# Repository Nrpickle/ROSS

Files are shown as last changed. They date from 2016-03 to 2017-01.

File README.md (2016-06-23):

# ROSS
Robotic Oceanographic Surface Sampler "lower level" code repo

This code covers anything that is not "user-servicable", which includes all of the firmware for the Kayak, as well as some miscellaneous lower level scripts for the Raspberry Pi.

## Software

All "software" for this project (e.g. things run on ground stations) can be found in the appropriate BitBucket repo. Contact [Nick McComb](mccombn@oregonstate.edu) or [Jasmine Nahorniak](mailto:jasmine@coas.oregonstate.edu) for access/more information.

## Firmware

"Firware" as defined for this project, is anything that runs on a microcontroller (e.g. doesn't use an Operating System). This Repo contains code for the following sub-projects:

### On/Off Switch

The primary On/Off switch for the kayak.

This box also provices a thrice-redundant GPS logging mechanism, that is independent of all other systems (besides power).

### Power Distribution Board (PDB)

This primarialy handles power distribution inside of the electrioncs box. 

For more information on this PCB, visit its dedicated documentation page [here](http://nickmccomb.net/printed-circuit-boards/ross-pdb).

For more information on the firmware for the microcontroller on this PCB, visit the subdirectory [here](https://github.com/Nrpickle/ROSS/tree/master/PDB/PowerDistribution).

### Winch / EBox Auxillary Programming

For more information on this PCB, visit its dedicated documentation page [here](http://nickmccomb.net/printed-circuit-boards/ross-ebox-auxillary).

### XTend Daughterboard

For more information on this PCB, visit its dedicated documentation page [here](http://nickmccomb.net/printed-circuit-boards/xtend-daughterboard).

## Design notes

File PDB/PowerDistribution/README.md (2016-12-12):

## Power Distribution Board

This board provides many features for the EBox for the ROSS project.

### Firmware Versioning

This page will describe released versions of this fiwmare and any important changes made. The firmware version will be bumped everytime a new version is pushed onto hardware.

#### Version .3

Released on 6/20/2016 for version 2.2 of the PDB hardware.

This is the first major implementation of the firmware, and while all the individual pieces of the firmware has been tested, ~~it hasn't made it out into the world yet~~ it was deployed in Alaska! This code has been extremely stable, with no bugs as of yet (December 2016).

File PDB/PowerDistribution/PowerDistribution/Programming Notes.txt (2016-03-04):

Settings Switch requires pull up resistors internal to uC

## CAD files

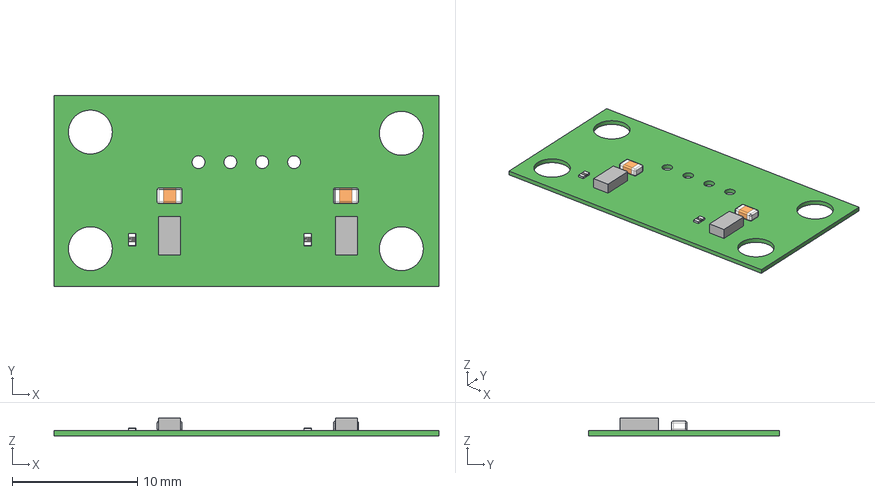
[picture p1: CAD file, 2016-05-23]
Winch/HallEffectSensors/HalleffectSensorsStepFile2.step
30.7 x 15.2 x 1.41 mm
Board
Extruded x 2
0402_SMD_Resistor x 2
User_Library-0805_SMD_Capacitor x 2

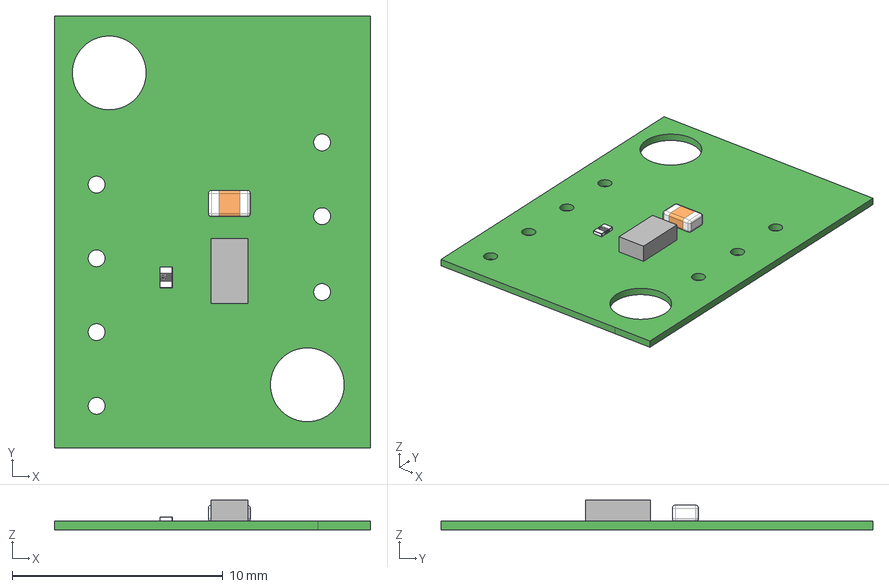
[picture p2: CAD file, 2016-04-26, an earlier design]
Winch/HallEffectSensors/HalleffectSensorsStepFile.step
15.0 x 20.5 x 1.41 mm
Board
Extruded
User_Library-0805_SMD_Capacitor
0402_SMD_Resistor

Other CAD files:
Winch/HallEffectSensors/HalleffectSensorsStepFile2_1.step
Winch/HallEffectSensors/HalleffectSensorsStepFileRev2.step

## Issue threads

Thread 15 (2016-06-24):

Debouncing winch hall effect sensors

Nrpickle, 2016-06-24:
Note "enhancement" tag.

This would essentially mean, that once the switch hits, you move a _small_ amount futher, so that you are for sure within the activation range of the hall effect, and not just on the edge. This would have to be done carefully, however.

Nrpickle, 2016-07-06:
Note this might actually be acheived by the inherient 500mS slowdown provided by the acceleration code...

Closed 2016-07-07.

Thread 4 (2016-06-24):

Arduino Servo Library doesn't output the values that the servo is expecting

Nrpickle, 2016-06-24:
See what the ESC is expecting, and add the optional min and max to the Arduino Servo library

https://www.arduino.cc/en/Reference/ServoAttach

See the notes on the Toughbook to see what the ESC is looking for by default, and compare this to the card

RobJShannon, 2016-06-27:
Values in milliseconds
Neutral: 1.479
Max Forward: 1.910
Max Reverse: 1.048
Largest Braking Threshold: .15
View current values: Prog -> Basic -> Current Settings

Closed 2016-06-29.

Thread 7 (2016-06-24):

Create "setWinchSpeed" function (or equivalent)

Nrpickle, 2016-06-24:
This function will take into account "previous speed" and "desired speed" and make a change in a time that is configurable via a #define at the top of the program.

Something approaching ["S-Curve Acceleration"](http://www.ni.com/product-documentation/4824/en/) should be implemented. It would be 100% desired to use a sin() function to do this, but it might not be realistic. Really, this depends on how fast your control loop is running.

Nrpickle, 2016-06-24:
Make sure that the "stop" position is configurable

Nrpickle, 2016-06-24:
I would use something like this:

```c
enum {UP, DOWN, STOP} //setWinchPower direction enum

/*
desiredPower : 0 - 100 (percent), value does not matter when desiredDIrection is STOP
desiredDirection: reference the setWinchPower direction enum
*/
void setWinchPower(uint8_t desiredPower, uint8_t desiredDirection);  //Set the winch power
```

Nrpickle, 2016-06-24:
The
```c
void sendStatus()
```
function should reference _this_ function's "current" status, instead of other variables in the program

Nrpickle, 2016-06-24:
A good backend for this could be

```c
struct {
  uint8_t currentPower;
  uint8_t currentDirection;
} winch;
```

if you wanted to implement it as a class, then `currentPower` and `currentDirection` would be private variables that can only be accessed by the `setWinchPower()` function, to ensure that it is the only thing that sets speeds. It should also be the _only_ function that calls `ESC.write()`.

Nrpickle, 2016-06-24:
The ```ServoWriteMicroseconds()``` Arduino function might be handy [[link]](https://www.arduino.cc/en/Reference/ServoWriteMicroseconds)

Nrpickle, 2016-06-24:
Ooh.

Or, how about this?

```c
struct {
  uint8_t currentPower;
  uint8_t prevPower;
  uint8_t currentDir;
  uint8_t prevDir;
  uint8_t upToDate;
} winch;

static void setWinchPower(uint8_t desiredPower, uint8_t desiredDirection){
  //This function needs to be be able to be called continuously throughout the exectution of the program
  //You may want the transition time to be ~1 second and you can't go blocking your program for that entire time.

  if(desiredPower == winch.currentPower && desiredDirection == winch.currentDir){
    //set prevPower = currentPower
    return;  //We are up to date
  }

  //Scenario: we are currently at DOWN 40 and want to go to UP 80, sinusodially.

  //Scale output power to 0 to 200 (100 being stop) then you want

  uint8_t powerDifference = //Then relate this to a number that's negative if the speed needs to "decrease" on the 200 number scale

  int powerToSend  = ((sin(out of phase -pi/2) + 1)/2 * powerDifference) + winch.prevPower; //This should give you a number that ranges from 0 to 100 that sinusodially goes between the previous power, and the one you want

  winch.currentPower = powerToSend;

  //actually output the power

  //check if the're the same
  //if(winch.currentPower = desiredPower){
  //  winch.prevPower = desiredPower;
  }
}

```

RobJShannon, 2016-06-28:
(sin(pi(t/500)-pi/2)+1)/2

Closed 2016-06-29.

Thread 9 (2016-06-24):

Revisit status messages

Nrpickle, 2016-06-24:
Status messages should be at least 2Hz (Jasmine doesn't have to send them back to the base station at that rate, but she could...)

These should include current position (as they currently do), and if possible a "speed (rpm)" would be desired.

Nrpickle, 2016-06-24:
I would also expand the status message, so we get more than "BUSY" or "NOT BUSY". I'd reccomend something like the following:

```c
enum {
  WAITING_FOR_PACKET,
  START/STOP,
  STOPPING,  //Maybe include this? Not sure.
  PROFILING - DOWN,
  PROFILING - UP,
  BAD_CHECKSUM
}
```

Nrpickle, 2016-06-24:
Also, this should probably include the Hall Effect sensor's satus, if possible.

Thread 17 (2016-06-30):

Hall Effect Status

RobJShannon, 2016-06-30:
Include HES state and error handle that returns in and maintains position if more than 6 revolutions go out without lower sensor engaging.

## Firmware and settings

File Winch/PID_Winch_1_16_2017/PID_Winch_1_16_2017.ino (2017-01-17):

#include <Statistic.h>

//Winch control version for use with the XLX green ESC
//Note: speeds and other variables need to be adjusted
//Note: code only checks for HES output when within slowing distance. May need to be changed.

#define DEBUG //Uncomment to print debugging information via serial
//#define TEST //Uncomment to run test with fake resistance
#define DOPID //Uncomment to run PID loop
Statistic myStats;
struct Winch_TYPE {
  uint8_t currentSpeed;
  uint8_t prevSpeed;
  uint8_t currentDir; // UP,DOWN,STOP defined in enum
  uint8_t prevDir;
  uint8_t prevDesiredDir;
  uint8_t prevDesiredSpeed;
} winch;

#include <Servo.h>
#include <Encoder.h>
#include <Timer.h>
#include <PID_v1.h>

Servo ESC; //Create ESC object
Encoder winchEncoder(3,2); //Create encoder object
Timer statusTimer; //Create a timer for sending status messages
  
enum{ //Assign integer values to each direction
  UP,
  DOWN,
  STOP
};

enum{  //Assign integer values to each state
  CHECK_BUFFER,
  CONTROL_WINCH,
  MAINTAIN
};

#define ENCODER_OPTIMIZE_INTERRUPTS
//Maximum, minimum, and neutral pulse widths in microseconds 
//ESC 1: 1910, 1479, 1048
//ESC 2: 1980, 1534, 1086
//ESC 3 (green XLX 12/1/2016): 2405, 1475, 545  
#define MAX_FORWARD 2405 //Maximum, minimum, and neutral pulse widths in microseconds
#define NEUTRAL 1475
#define MAX_REVERSE 545
#define REV(x) 3936*x //Converts revolutions into encoder pings

//Speed constants
#define SLOW_DIST 15 //Distance in revolutions from full upright to begin changing winch speed in
#define LIFT_SPEED 45//Speed for lifting the A-frame when finishing a profile
#define MAINTAIN_SPEED 40 //Speed for lifting the A-frame when maintaining
#define FAST_IN_SPEED 50 //Speed for returning fast AND maintaining
#define SLOW_IN_SPEED 30 //Speed for returning slow AND maintaining

//Define remote start/stop pins
#define remoteStartPin 5
#define remoteStopPin 6
#define remoteStartLED 7
#define remoteStopLED 8
#define startTime 750 //How long remote start is held HIGH in milliseconds
//Define sensor pins
#define downPin 10//Hall Effect sensor indicating lowered position (no longer used)
#define downLED 13
#define upPin 11 //Hall Effect sensor indicating upright position
#define upLED 15
//Define analog pins
#define resistancePin 8 //fishing rod strain gauge resistance (analog pin)

//Define PID tuning parameters (must be >= 0)
//error = desired - input
//output = Kp*error + integral(Ki*error) - Kd*(input - lastinput)
double Kp = .035; // proportional - reacting to current error
double Ki = 0; // integral - reacting to error over time
double Kd = 0; // derivative - reacting to change in error
const int KDir = DIRECT;  // if DIRECT, +INPUT leads to +OUTPUT, if REVERSE, +INPUT leads to -OUTPUT

// resistance calibration settings for the fishing rod
double straightResistance = 0; //ohms - rod straight (no tension) (Daywa Custom Design (Dark Grey) - 800)
const double stopResistance = 0; //ohms - position of rod to send stop command (getting too slack) (should be about 722)
double bentResistance = 0; //ohms - rod bent (full tension) (should be about 620)
double desiredResistance = 600; //ohms - resistance to attempt to maintain at all times
double resistance = 0;  //TEST
double rodMultiplier = 0.95;

// frequency of status messages in ms
#ifdef DEBUG
    int statusFrequency = 1000;
#else
    int statusFrequency = 1000;
#endif

const double RAMP_TIME = 500; //Time it takes to change speed in milliseconds
const double RAMP_TIME_DOWN = 3000; //Ramp time at beginning of profile to prevent tangling
const float pi = 3.14159;
uint64_t t0 = 0; //Beginning time for speed change
int16_t speedDifference = 0; //Difference between desired and current speed
int parameters[7];
int incomingByte = 0;

int state = CHECK_BUFFER;
int firstbyte; //First byte to check consistency with RPI
int secondbyte = 0x00; //Second byte to check consistency with RPI
int header = 0;
int upperByte;
int lowerByte;

int checksum;
int buffSize = 0;
int speedOut;
int speedIn;
double speedTry;
long long depth;
bool motorRunning = false;
bool depthReached = false;
bool halt = false;
bool returned = true;
bool dataCorrupted = false;
bool go = false; //Used to specify if buffer is synced with RPI
bool kickstart = true; //used to kickstart pid for sinusoid

int timerActivate = 0; //Using this to piggyback off the timer for the status message

int warningCounter = 0; //used to tell if the rod has lost tension for a certain amount of time

int avgvalue = 0; //used for the stats values to average the resistance for min/max values

PID rodPID(&resistance, &speedTry, &desiredResistance, Kp, Ki, Kd, KDir); //Create PID object and links


void setup() {
  // put your setup code here, to run once:
  Serial1.begin(57600);
  #ifdef DEBUG
    Serial.begin(9600);
  #endif
  winch.currentSpeed = 100; //Initialize all struct values to stationary
  winch.prevSpeed = 100;
  winch.currentDir = STOP;
  winch.prevDir = STOP;
  winch.prevDesiredDir = STOP;
  winch.prevDesiredSpeed = 0;
  //Set pin modes
  pinMode(remoteStartPin, OUTPUT);
  pinMode(remoteStopPin, OUTPUT);
  pinMode(remoteStartLED, OUTPUT);
  pinMode(remoteStopLED, OUTPUT);
  pinMode(upLED, OUTPUT);
  pinMode(downLED, OUTPUT);
  pinMode(downPin, INPUT);
  pinMode(upPin, INPUT);
  //Initialize pin states
  digitalWrite(remoteStartPin, LOW);
  digitalWrite(remoteStopPin, HIGH);
  digitalWrite(remoteStartLED, LOW);
  digitalWrite(remoteStopLED, LOW);
   
  statusTimer.every(statusFrequency, sendStatus, sendWarning); //Send a status message every X milliseconds and send a warning if the rod has been straight for too long
  
  ESC.attach(9, MAX_REVERSE, MAX_FORWARD); //Connect ESC to pin 9 with maximum and minimum puse width values
  ESC.writeMicroseconds(NEUTRAL); //Start the winch in neutral
  delay(5000); //Allow ESC to receive neutral signal for proper amount of time

  rodPID.SetOutputLimits(-10, 10); //output given by PID controller is constrained (Should be used to change and input to the plant system)
  rodPID.SetMode(AUTOMATIC);

  while(!digitalRead(upPin) != true){ //waits for the A-frame to be all the way up
    changeSpeed(LIFT_SPEED, UP); //if for some reason it isn't we set the speed to go up 
    Serial1.println("Initial lift.");
  }
  changeSpeed(0, STOP);
  winchEncoder.write(0);
  returned = true;
  myStats.clear(); //Forces the "myStats" constructor to start with no data
}

void loop() {
  statusTimer.update();
  //checkResistance();  // keep this commented - it won't work with the PID loop 
  myStats.clear(); //make sure to clear old data from myStats constructor
  switch(state){
    
    case CHECK_BUFFER:

       if(buffSize == 7){ //Update parameters if the serial buffer is full (new packet fully received)
         updateParameters();
         Serial.println(header);
       }
       state = CONTROL_WINCH;
       
       break;
     
    case CONTROL_WINCH:
      if(header == 0xCD) //Set PID values using speedOut and speedIn (parameters[1-2]
      {
        Kp = speedOut/100;
        Ki = speedIn/100;
        header = 0;
      }

      if(header == 0xCA){ //calibration straight
        avgvalue = 0;
        while(avgvalue == 0){
          for(int i = 0; i < 50; i++){
            myStats.add(analogRead(resistancePin));          
            delay(100);
          }
          avgvalue = myStats.average() + 1;
          Serial.println(avgvalue);
        }
        straightResistance = avgvalue - 1;
        if(bentResistance > 0){
          desiredResistance =  straightResistance - ((straightResistance - bentResistance) * rodMultiplier); 
          
        }
        #ifdef DEBUG
          Serial.print("CAL STRAIGHT: ");
          Serial.println(straightResistance);
          Serial1.print("CALSTRAIGHT ");
          Serial1.println(straightResistance);
          Serial.print("DESIREDRESISTANCE: ");
          Serial.println(desiredResistance);
          //Serial1.println("TESTTESTTESTTEST");
        #endif
        header = 0; //stop entering this if statement
      }

      if(header == 0xCB){ //calibration bent
        avgvalue = 0;
        while(avgvalue == 0){
          for(int i = 0; i < 50; i++){
            myStats.add(analogRead(resistancePin));          
            delay(100);
          }
          avgvalue = myStats.average() + 1; //Make sure the code exits the while loop
        }
        bentResistance = avgvalue - 1; //Remove the extra 1 value
         if(straightResistance > 0){
          desiredResistance =  straightResistance - ((straightResistance - bentResistance) * rodMultiplier); //Calculates our tension value we want. It will be 95% of the difference between our max and min values that were calibrated     
           }
        #ifdef DEBUG
          Serial.print("CAL BENT: ");
          Serial.println(bentResistance);
          Serial1.print("CALBENT ");
          Serial1.println(bentResistance);
          Serial.print("DESIREDRESISTANCE: ");
          Serial.println(desiredResistance);
        #endif
        header = 0; //stop entering this if statement
       }
       
       if(header == 0xCC){ //STOP:Halt
         changeSpeed(0, STOP);
         halt = true;
         depthReached = true;
         returned = true;
       }
         
       if(header == 0xAA){//STOP:Return at full speed
         //changeSpeed(0, STOP);
         depthReached = true;
         if(!digitalRead(upPin) == false) //Return the winch to its upright position and maintian (only if the winch isn't already up)
           changeSpeed(FAST_IN_SPEED, UP);
         if(!digitalRead(upPin) == true && winchEncoder.read() <= REV(SLOW_DIST)){
           changeSpeed(0, STOP);
           winchEncoder.write(0);
           returned = true;
           header = 0; //stop entering this if statement
         }
       }
       
       if(header == 0xBB){//STOP:Return slower
         //changeSpeed(0, STOP);
         depthReached = true;
         if(!digitalRead(upPin) == false) //Return the winch to its upright position and maintian
           changeSpeed(SLOW_IN_SPEED, UP);
         if(!digitalRead(upPin) == true && winchEncoder.read() <= REV(SLOW_DIST)){
           changeSpeed(0, STOP);
           winchEncoder.write(0);
           returned = true;
           header = 0; //stop entering this if statement
         }
       }
       
       if(header == 0xEE)//Stop the motor
         remoteStop(); 
       
       if(header == 0xDD)//Start the motor
         remoteStart();
       
       if(header == 0xDA)//Take a profile - normal operation
         takeProfile();
         
       if(returned == true && halt == false) //If all the other header values aren't true then go to this
       {
         state = MAINTAIN;
       }
       else
       {
         state = CHECK_BUFFER;
       }
       break;
     
    case MAINTAIN:
       kickstart = true;
        //Serial.println("MAINTAIN");
       //if(!digitalRead(upPin) == false || !digitalRead(downPin) == true)
       if(!digitalRead(upPin) == false)   //if the winch isn't in the up position then
        { 
         changeSpeed(MAINTAIN_SPEED, UP);//change our speed to go up at the maintain speed
         //Serial.println("I'M SETTING THE SPEED TO BE UP AT MAINTAIN SPEED");
       }
       else{
         //Serial.println("I'VE SET THE SPEED TO BE 0 AND STOPPED");
         changeSpeed(0, STOP); //when we've reached the top then stop
         winchEncoder.write(0); //reset the winch encoder counter to 0
         //Serial.println("I'VE RESET THE WINCH COUNTER");
         returned = true;
       }
       state = CHECK_BUFFER;
       break;
   
  } //end switch
  delay(2);
} //end loop

void changeSpeed(uint8_t newSpeed, uint8_t newDir)  {
  double ramp = RAMP_TIME;
  if(newDir == DOWN)
    ramp = RAMP_TIME_DOWN;

  //Serial.println(newSpeed);
  //If we want to go UP
  if(newDir == UP){
    newSpeed = 100 - newSpeed;
    //winch.currentDir = UP;
  }
  //If we want to go down
  else if(newDir == DOWN){
    newSpeed = 100 + newSpeed;
    //winch.currentDir = DOWN;
  }
  //Else we want to STOP
  else{
    newSpeed = 100;
    //winch.currentDir = STOP;
  }
  #ifdef DEBUG
    //Serial1.print("[Desired: ");
    //Serial1.print(newSpeed);
    //Serial1.print(" Current: ");
    //Serial1.print(winch.currentSpeed);
    //Serial1.println("]");
  #endif
  

  //Check if no change is needed (if we are going the desired speed and direction)
  if(newDir == winch.currentDir && newSpeed == winch.currentSpeed)
  {  //If the command is to continue moving the same speed and direction then don't do the sinusoid
    winch.prevSpeed = winch.currentSpeed;
    winch.prevDesiredSpeed = newSpeed; //Next time we write a new speed we know it will be at t0, the beginning of a speed change
    winch.prevDesiredDir = newDir;
    #ifdef DEBUG
      //Serial1.println("[REACHED END CASE]");
    #endif
    return;   //...return without altering speed (And ignoring EVERYTHING below this)
  }

    //This will catch if we have gotten to this spot while the previous call to the function was "no change requested"
    if(winch.prevDesiredSpeed != newSpeed && winch.prevDesiredDir != newDir)
    {  //Even though the newspeed = prevspeed will be true, this only activates when changing direction
      //If that's the case, then we want to initialize the acceleration
      t0 = millis();  //Start a timer for the sinusoid function
      speedDifference = newSpeed - winch.prevSpeed;
      //Avoid errors comparing different data types. If the difference is a negative value, make it slightly more negative. Same for a positive speed difference. 
      if(speedDifference < 0)
        speedDifference -= 1;
      else if (speedDifference > 0)
        speedDifference += 1;
    }   
    if(kickstart == true) {
    uint64_t deltaT = millis() - t0; //Keep relative time for the sinusoid (this will not activate if we've reached the speed we want
    winch.currentSpeed = (double)winch.prevSpeed + (double)speedDifference*.5*(1-cos((pi*(double)deltaT)/ramp));//Accelerate sinusoidally
    }
    else{
      winch.currentSpeed = newSpeed;
    }

  constrain(winch.currentSpeed, 0, 200); //Do not write above or below the maximum pulse widths
 // Serial.println("SPEED IS:   ");
 // Serial.println(winch.currentSpeed);
  uint16_t speedToWrite = map(winch.currentSpeed, 0, 200, MAX_REVERSE, MAX_FORWARD); //Convert from sinusoid magnitude to pulse width
  ESC.writeMicroseconds(speedToWrite); //Write the scaled value
  #ifdef DEBUG
    //Serial1.println(speedToWrite);
  #endif 
  if(winch.currentSpeed == newSpeed)
    winch.prevSpeed = newSpeed; //Set the starting point for the next speed change
    
  if(winch.currentSpeed > 100)
    winch.currentDir = DOWN;
  else if(winch.currentSpeed < 100)
    winch.currentDir = UP;
  else if(winch.currentSpeed == 100)
    winch.currentDir = STOP;
    
  winch.prevDesiredSpeed = newSpeed; //Next time we write a new speed we know it will be at t0, the beginning of a speed change
  winch.prevDesiredDir = newDir;
}

void serialEvent1()
{
  if(Serial1.available()){
   
   if (go){ //check to see if the go statement is true (Data is synced)
     parameters[buffSize] = Serial1.read();
     buffSize++;
   }
   else{  //If the go statement isn't true, wait until the data is synced and then make go statement true

        firstbyte = Serial1.read(); //Read the first byte coming from the RPI
    
        if((firstbyte == 255) && (secondbyte == 255)){
          go = true;
        }
        else{
          secondbyte = firstbyte; //store value to check again
          go = false;
        }
   }
  }
}

void updateParameters(){
  header = parameters[0];
  speedOut = parameters[1]; //Save array contents to corresponding variables
  speedIn = parameters[2];
  upperByte = parameters[3];
  lowerByte = parameters[4];
  checksum = parameters[5];
  Serial.println(header);
  Serial.println(speedOut);
  Serial.println(speedIn);
  Serial.println(upperByte);
  Serial.println(lowerByte);
  Serial.println(checksum);
  buffSize = 0; //Reset buffer size and control variables
  kickstart = true; //reset kickstart for another profile
  go = false; //reset the go condition to check data again for consistency 
  secondbyte = 0x00; // reset second byte to zero
  warningCounter = 0;
  depthReached = false;
  halt = false;
  if(checksum == (((speedOut ^ speedIn) ^ upperByte) ^ lowerByte)){
    upperByte = upperByte << 8;
    depth = upperByte + lowerByte;
    depth = REV(depth); //pings/revolution
    speedOut = speedOut*100/254; //Scale from 0-254 to 0 - 100
    speedIn  = speedIn*100/254; //Scale from 0-254 to 0 - 100
    dataCorrupted = false;
  }
  else{
    depth = 0;
    speedOut = 0;
    speedIn = 0;
    dataCorrupted = true;
  } 
}

void sendStatus(){
  Serial1.print("STATUS ");
  Serial.println("STATUS");
  if(dataCorrupted == false){
    if(returned == true){
      Serial1.print("1  "); //Ready
    }
    else{
      Serial1.print("0  "); //Busy
    }
  }
  else{
    Serial1.print("3  "); //Data corrupted
    dataCorrupted = false;
  }
  Serial1.print("Dir ");
  if(winch.currentDir == UP)
    Serial1.print("up  ");
  else if(winch.currentDir == DOWN)
    Serial1.print("down  ");
  else if(winch.currentDir == STOP)
    Serial1.print("stationary  ");
 
  Serial1.print("Rev ");
  long long pingsFromSurface = winchEncoder.read();
  pingsFromSurface = pingsFromSurface/3936;
  long revsFromSurface = (long) pingsFromSurface;
  Serial1.print(revsFromSurface);
  Serial1.print(" Kp ");
  Serial1.print(Kp);
  Serial1.print(" Ki ");
  Serial1.print(Ki);
  Serial1.print(" Res ");
  Serial1.println(analogRead(resistancePin));
  
  
  Serial.print("Rev ");
  Serial.println(revsFromSurface);
  Serial.print("Speed: ");
  Serial.println(winch.currentSpeed);
  Serial.print("Res: ");
  Serial.println(analogRead(resistancePin));
  Serial.print("Desired Resistance:  ");
  Serial.println(desiredResistance);
  
  #ifdef DEBUG
    //Serial.print("[Resistance: ");
    //Serial.print(resistance);
    //Serial.println("]");
  #endif
}

inline void remoteStart(){
  if (motorRunning == false){ //Prevent remote start from executing if motor already running
    digitalWrite(remoteStopPin, LOW);
    digitalWrite(remoteStartPin, HIGH);
    digitalWrite(remoteStartLED, HIGH);
    delay(startTime);
    digitalWrite(remoteStartPin, LOW);
    digitalWrite(remoteStartLED, LOW);
    motorRunning = true;
  }
}

inline void remoteStop(){
  if(motorRunning == true){
    digitalWrite(remoteStopPin, HIGH);
    digitalWrite(remoteStopLED, HIGH);
    motorRunning = false;
  }
}

void takeProfile(){
   if(depthReached == false){
//    if(!digitalRead(downPin) == false){//Slowly let A-frame down from upright position
//      changeSpeed(30, DOWN);
//      returned = false;
//    }
     if((winchEncoder.read() < depth)){
       doPID(speedOut, DOWN);
       returned = false;
     }
     else if(winchEncoder.read()>= depth){
       changeSpeed(0, STOP);
       Serial.println("I'VE REACHED THE END OF THE PROFILE, SET THE SPEED TO 0 AND STOP"); //debug change speed when reached depth desired
       depthReached = true; 
       returned = false;
       kickstart = true;
     }
  }
  else if((depthReached == true) && (halt == false)){
    
    
      if(!digitalRead(upPin) == true){ //Stop when A-frame is in full upright position
        changeSpeed(0, STOP);
        winchEncoder.write(0); //Account for line stretching - reset after each cast
        returned = true;
        Serial.println("DONE PROFILE");
        header = 0; //Will go straight into maintain mode rather than use take profile to maintain position
      }
     
      else if(winchEncoder.read() > REV(SLOW_DIST)){ //checks to see if we're within the slow_dist revolutions (5 revs)
      changeSpeed(speedIn, UP);
      //Serial.println("Going speedIn in the UP direction"); //Debug speed in
      returned = false;
    }
      else{ //We reached the depth and we're within 5 revs
        changeSpeed(LIFT_SPEED, UP); //This is the speed the winch will go when within five revolutions
      //Serial.println("Going Lift_Speed in the UP direction"); //debug speed in
      }
    }
  }


void checkResistance(){
  #ifdef TEST
    resistance = resistance - 1;
  #else
    resistance = analogRead(resistancePin);
  #endif
  if(resistance < stopResistance){
    changeSpeed(0, STOP);
    depthReached = true;  //we are acting like the cast reached the bottom of the profile
    halt = false; //we are acting like the cast reached the bottom of the profile
    returned = false;
    header = 255; //we need it to proceed as if it was at the bottom of a profile, even if it wasn't doing a profile
    #ifdef TEST
      resistance = bentResistance;
    #endif   
    #ifdef DEBUG
      Serial1.println("[RESISTANCE TOO LOW - STOPPED WINCH AND RETURNING TO SURFACE]");
    #endif
  }
}
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

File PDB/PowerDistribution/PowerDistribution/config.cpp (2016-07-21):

/*
 * config.cpp
 *
 * Created: 5/26/2016 10:12:21 AM
 *  Author: Nick McComb | www.nickmccomb.net
 */ 

#include "config.h"

extern RSSI_type RSSI;

void configureADCs(){
	// Batt Input Voltage
	// Halve Input
	//Set to single ended input
	//Set to 12-bit mode
		
	ADCA.CTRLB = (ADC_RESOLUTION_MT12BIT_gc | ADC_CONMODE_bm);	//Sets resolution to 12 bit and sets conversion mode to signed
	ADCA.REFCTRL = ADC_REFSEL_AREFA_gc;                              //Reference the "rail splitter" 2.5v reference
	ADCA.EVCTRL = 0; //Disable events
	ADCA.PRESCALER = ADC_PRESCALER_DIV512_gc;
	ADCA.CALL = ReadCalibrationByte(offsetof(NVM_PROD_SIGNATURES_t, ADCACAL0));
	ADCA.CALH = ReadCalibrationByte(offsetof(NVM_PROD_SIGNATURES_t, ADCACAL1));
	_delay_us(400);
	//ADCA.CH0.AVGCTRL = ADC_SAMPNUM_256X_gc;
	ADCA.CH0.CTRL = (ADC_CH_GAIN_1X_gc | ADC_CH_INPUTMODE_DIFFWGAINL_gc);
	ADCA.CH0.MUXCTRL = (ADC_CH_MUXPOS_PIN8_gc | ADC_CH_MUXNEGL_PIN1_gc);  //Init the ADC MUX to use the PIN8 input
																	 //and set the negative input to the GND
																     //reference on PORTA PIN1
	ADCA.CH0.INTCTRL = 0; // Set COMPLETE interrupts
	ADCA.CTRLA = ADC_ENABLE_bm;
	
	/*
	//ADCA.REFCTRL 
	
	//Temperature sensor is on PA0 (ADC0)
	//ADCA.CH0.CTRL = ADC_CH_INPUTMODE_SINGLEENDED_gc;

	//Select Pin8 group setting
	//ADCA.CH0.MUXCTRL = ADC_CH_MUXPOS_PIN0_gc;
	
	//Enable the ADC
	//ADCA.CTRLA = ADC_ENABLE_bm;
	//Wait a ms for ADC to start up. This is _way_ overkill. Spec is 24 ADC clock cycles
	//_delay_ms(1);
	//ADCA.CH0.CTRL = ADC_CH_START_bm;
	//
	//ADCA.CTRLA |= ADC_CH8START_bm;
	*/	
}	

void configureExternalOscillator(){
	int temp = 0;																			//Temporary variable for helping avoid 4 clock cycle limitation when updating secure registers
		
	//Enable external 4MHz oscillator
	OSC.XOSCCTRL = (OSC_FRQRANGE_2TO9_gc | OSC_XOSCSEL_XTAL_16KCLK_gc);						//Set external oscillator to be between 2 and 9 MHz and select it
	OSC.CTRL |= OSC_XOSCEN_bm;																//Enable the external oscillator
	while(!(OSC.STATUS & OSC_XOSCRDY_bm)){ERROR_SET();};									//While the external oscillator is not ready, set the error led
	ERROR_CLR();																			//Clear the error led if the external oscillator has stabilized
		
	//Enable phase locked loop to multiply external oscillator by 8 to get 32MHz
	temp = ((OSC_PLLSRC_XOSC_gc & OSC_PLLSRC_gm) | (OSC_PLLFAC_gm & 8));					//Set the external oscillator as the clock source for the pll and set to multiply by 8
	CCP = CCP_IOREG_gc;																		//Disable register security so we can update the pll control settings
	OSC.PLLCTRL = temp;																		//Write pll control settings to register
	OSC.CTRL |= OSC_PLLEN_bm;																//Enable the pll
	while(!(OSC.STATUS & OSC_PLLRDY_bm)){ERROR_SET();};										//While the pll is not ready, set the error led
	ERROR_CLR();																			//Disable the error led if successfully stabilized
		
	//Set system pll clock divisions and set up as source for all system clocks
	temp = ((CLK_PSADIV_gm & CLK_PSADIV_1_gc) | (CLK_PSBCDIV_gm & CLK_PSBCDIV_1_1_gc));		//Set system to use pll divided by 1 (no division)
	CCP = CCP_IOREG_gc;																		//Disable register security so we can update the clock source division setting
	CLK.CTRL = temp;																		//Write division settings to register
		
	temp = CLK_SCLKSEL_PLL_gc;																//Set pll as system clock source
	CCP = CCP_IOREG_gc;																		//Disable register security so we can update the system clock
	CLK.CTRL = temp;																		//Write clock source settings to register
	
	
}
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

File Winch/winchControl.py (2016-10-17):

from sys import argv
import serial
from time import sleep

def closeCheck():
	if ser.isOpen() == False:
		print "Port closed"	
	elif ser.isOpen() == True:
		print "Port is still open"
		ser.close()
		closeCheck()
		
ser = serial.Serial(
    port='COM30',\
    baudrate=57600,\
    parity=serial.PARITY_NONE,\
    stopbits=serial.STOPBITS_ONE,\
    bytesize=serial.EIGHTBITS,\
    timeout= None) #Open serial port
ser.close()

parameters = [0,0,0,0,0,0,0]
stop = int(argv[4])

if stop == 0:
	header = 255
	speedOut = int(argv[1]) #Collect runtime parameters
	speedIn = int(argv[2])
	depth = int(argv[3])
	upperDepthByte = depth >> 8
	lowerDepthByte = depth & 0xFF
	checksum = (((speedOut ^ speedIn) ^ upperDepthByte) ^ lowerDepthByte) #XOR all variables to create checksum
	footer = 255
	parameters = [header , speedOut, speedIn, upperDepthByte, lowerDepthByte, checksum, footer] #Save parameters in array
elif stop == 1:
	for x in range(len(parameters)):
		parameters[x] = 0xAA
elif stop == 2:
	for x in range(len(parameters)):
		parameters[x] = 0xBB
elif stop == 4:
	for x in range(len(parameters)):
		parameters[x] = 0xCC	
elif stop == 8:
	for x in range(len(parameters)):
		parameters[x] = 0xDD #remote start
elif stop == 16:
	for x in range(len(parameters)):
		parameters[x] = 0xEE #remote stop

print parameters

ser.open()
for x in parameters:
	x = chr(x) #cast to char to make single bite
	ser.write(x)
	sleep(0.1)

ser.close()
closeCheck()
#while(1):
#	print(ser.readline())
	
	

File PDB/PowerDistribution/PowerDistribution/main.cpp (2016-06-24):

/*
 * PowerDistribution.cpp
 * 
 * Made for the ROSS project. To view the code for this project, go to: 
 * https://github.com/Nrpickle/ROSS
 *
 * Created: 12/22/2015
 * Author : Nick McComb | nickmccomb.net
 
 TODOs
 - Enable all current sensing appropriately
 - Enable current sense fault detection (is this actually desired?)

 COMPLETED
 - Enable PWM passthrough / steering control
 - Enable PWM Override
 - Enable On/Off passthrough
 - Ensure accurate ambient temperature sensor measurements
 */ 

#define FIRMWARE_VERSION_STR ".2"
#define FIRMWARE_VERSION .2

#include "main.h"

volatile RSSI_type RSSI;

//Global Variables *gasp*
volatile int toggle = 0;
volatile int temp = 1000;
uint8_t remoteInput = 0;
uint8_t remoteOutputCountdown = 0;  //Count to "only output start stop state for 5 states"

uint8_t  pixhawkOverride = 0;			//Shall we override the Pixhawk's PWM signal? :sunglasses:
uint16_t manualPWMOutput = 1500;		//uS of desired override PWM output
uint16_t pixhawkOverrideCountdown = 0;	//Amount of message cycles to maintain override

#define REMOTE_START_CHECK 0x1
#define REMOTE_STOP_CHECK  0x2

int main(void)
{
	configureIO();
	configureExternalOscillator();
	configureUSART();					//Set up for 57600 Baud
	configureTimerCounter();
	configureADCs();
	configureRTC();
	configureXCL();
	configureSerialNumber();
		
	LOW_LEVEL_INTERRUPTS_ENABLE();
	MED_LEVEL_INTERRUPTS_ENABLE();
	HIGH_LEVEL_INTERRUPTS_ENABLE();
	sei();								//Enable global interrupts
	
	uint8_t receivedUSARTData;
	
	RSSI.measuring = NOT_MEASURING;
	RSSI.timeDifference = 0;
	RSSI.sampleCount = 0;

	//Init string with basic documentation
	SendStringPC("\n\r#[INIT ROSS PDB]\n\r");
	SendStringPC("#Firmware version ");
	SendStringPC(FIRMWARE_VERSION_STR);
	SendStringPC("\n\r#Serial Number: ");
	if(serialNumber == -1)
		SendStringPC("NOT SET");
	else
		SendNumPC(serialNumber);
	SendStringPC("\n\r#Msg format: Electronics Batt Volt | Rear Batt Volt | Ebox Temperature | 5v_SYS Curr | 5v_Comp Curr | Throttle Current | XTend RSSI | \"Remote Input\" \n\r");
	
    while (1) 
    {

		_delay_ms(1);

		//Check for commands from the computer
		if(USART_IsRXComplete(&COMP_USART)){
			receivedUSARTData = USART_GetChar(&COMP_USART);
			
			//Check if the inputted command is within the range to be
			//forwarded to the ON/OFF switch
			if(receivedUSARTData >= 30 && receivedUSARTData <= 65){
				SendCharONOFF(receivedUSARTData);
			}
			
			//Rear relay processing
			if(receivedUSARTData == 'y')
				REAR_RELAY_SET();
			else if(receivedUSARTData == 'n')
				REAR_RELAY_CLR();
			
			//Override canceling
			if(receivedUSARTData == 70){  //Then we need to cancel our override (if it exists)
				pixhawkOverride = 0;
				pixhawkOverrideCountdown = 0;
			}
			
			//Steering Override processing
			if(receivedUSARTData >= 71 && receivedUSARTData <= 87){		//Then we need to process a PWM override
				pixhawkOverride = 1;
				manualPWMOutput = receivedUSARTData * 50 - 2450;  //This will generate the correct output per https://goo.gl/7wYL6b
				if(CHECK_DIP_SW_2()){	//5 second update time
					if(TCC4.PER == TC_1024_100MS)
						pixhawkOverrideCountdown = 50;
					else if(TCC4.PER == TC_1024_500MS)
						pixhawkOverrideCountdown = 10;
					else
						pixhawkOverrideCountdown = 50;
				}
				else {	//1 second update time
					if(TCC4.PER == TC_1024_100MS)
						pixhawkOverrideCountdown = 10;
					else if(TCC4.PER == TC_1024_500MS)
						pixhawkOverrideCountdown = 2;
					else
						pixhawkOverrideCountdown = 10;
				}
			}
		}		
		
		//Check for commands from the ON/OFF Switch
		if(USART_IsRXComplete(&ONOFF_USART)){
			receivedUSARTData = USART_GetChar(&ONOFF_USART);
			//CHECK FOR IF START OR STOP COMMAND
			if(receivedUSARTData == 10){	//Remote start requested
				remoteInput = REMOTE_START_CHECK;
				remoteOutputCountdown = STATIC_STATUS_OUTPUT_COUNT;
			}	
			else if(receivedUSARTData == 20){	//Remote stop requested
				remoteInput = REMOTE_STOP_CHECK;
				remoteOutputCountdown = STATIC_STATUS_OUTPUT_COUNT;
			}
		}
		
		if(pixhawkOverride){	//If we do want to override the signal
			TC_PWM_SET(manualPWMOutput);	//Output the desired override PWM output
		}
		else {  //We don't want to overrride the signal
			TC_PWM_SET(steeringPWMPeriod);	//Output the Pixhawk PWM signal
		}
		
		if(broadcastStatus){  //This variable becomes true every interval that the user wants info reported
			broadcastStatus = 0;
			
			TCC4.CNT = 0;	//We want to ensure the counter is 0 so that we can 
							//have a consistent report time. (We don't want to throw
							//out the accuracy of the TC)
			
			//Calculated desired output values
			double EBoxTemp = getEBoxTemperature();
			double electronicsBatteryVoltage = getBatteryVoltage(ELECTRONICS);
			double rearBatteryVoltage = getBatteryVoltage(REAR_BATT);
			//double XTendCurrent = getSystemCurrent(THROTTLE);
			double sysCurrent = getSystemCurrent(SYS_5V);
			double compCurrent = getSystemCurrent(COMP);
			double throttleCurrent = getSystemCurrent(THROTTLE);
			//double zero = 0.0;
			
			getXTendRSSI();	//This is better here than in an interrupt because the frequency
							//of the interpreted PWM signal is so high, there's no reason
							//to sample it continuously. Also, on the same side of the coin,
							//it is quick to sample.
			
			
			//Actually output the desired values
			//Not the most elegant code in the world, but it works...
			
			SendFloatPC(electronicsBatteryVoltage);	//Send the battery voltage
			SendStringPC("|");
			if(rearBatteryVoltage < 0)
				SendFloatPC((double) 0);
			else
				SendFloatPC(rearBatteryVoltage);		//Send the rear battery voltage
			SendStringPC("|");
			SendFloatPC(EBoxTemp);	//Send the EBox Temperature
			SendStringPC("|");
			SendFloatPC(sysCurrent);		//Send 5v_SYS Curr
			SendStringPC("|");
			SendFloatPC(compCurrent);		//Send computer Curr (RPi)
			SendStringPC("|");
			SendFloatPC(throttleCurrent);
			SendStringPC("|");
			SendNumPC(RSSI.value);
			if(RSSI.value == 0)
				SendStringPC("0");
			SendStringPC((char *)"|");
			SendNumPC(remoteInput);
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

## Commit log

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2015-12-30 Enabled 32Mhz Internal Oscillator
    [main.cpp]
2016-01-27 Create first draft of winch packet structure
    [Winch Packet Structure.xlsx]
2016-02-17 Update Winch Control
    Allow Teensy to send data
2016-02-17 Revert "Update Winch Control"
    This reverts commit 2a37cfbdc36ae5119589c883f9aede79d5bbe14c.
    [winchControl.py]
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2016-03-04 [Not working] Attempting to setup ADC milestone
    Actually changes values with different inputs... Not accurate though.
    [main.cpp]
2016-03-04 ADCs working, mostly
    So it turned out we were missing a setting (ADC_CONMODE_bm) that set the
    adc to signed mode. Kind of important. Now, adc values are a bit more in
    line with what I'd expect. However, they still fluctuate so maybe it
    need a filter cap? I also changed the resolution mode to "more than" 12
    bit, which lets you use the avgctrl register to play with some built in
    averaging and oversampling. It may help, but a simple average function
    may do as well and be faster.
    [main.cpp]
2016-04-26 cast sent byte as char
    This is the first working Windows serial python script. It controls
    overall speed, depth, and duration/units. For use with first working
    revision of serialWinchControl Arduino code.
2016-04-26 remove test code
    This is the first fully functioning version of the Windows serial
    communication code for Arduino. Does not utilize checksum or error
    checking.
    [SerialWinchControl.ino]
2016-04-26 update packet structure and implement stop
    Python code now accepts speed in, speed out, depth, and a stop
    condition. Stop condition behaves differently if argument is 1, 2, or 3.
    Ignored otherwise. Arduino code is cleaned up but ready to accept new
    parameters.
2016-04-26 update stop bit in python code and arduino params
    added remote stop and start to python code
    arduino code saves new incoming parameters to updated variables
2016-04-26 create case statements for FSM
    Seven states have been created. Still need code for fast and slow in as
    well as checking for new serial input for stop.
2016-04-26 Create testing programs
    Programs to test reed switch and winch stopping distance
2016-04-26 Update Winch Control to utilize reed switches
    Issue with switches activating due to vibration. Exploring debounce
    options.
    [SerialWinchControl.ino]
2016-04-26 Create program to take pictures with boat's camera
2016-04-26 Fix code to properly edit matrix values
    Code now properly sets all values in parameter matrix to the expected
    number when corresponding stop bit is provided.
    [winchControl.py]
2016-04-26 Revise state machine
    Attempted to revise state machine to accept different stop conditions.
    Beginning second revision. This current version can run winch with halt
    commands.
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2016-04-26 Modify code to facilitate testing
    Wrote LED pin HIGH for debugging. Sent a test message rather than status
    in sendStatus function. Also decreased timer duration from 5000000 to
    5000ms.
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2016-04-26 Make code compatible with Aux. Board
    Serial becomes Serial1. serialEvent() becomes serialEvent1(). Hall
    Effect sensors removed (will be added with next revision of Aux. Board).
2016-04-26 Create files for PCB fabrication
    [HalleffectSensorsStepFile.step]
2016-04-26 Implemented many features on PDB
    Voltage Monitoring, Relay Control, Plotting, Timer/Counters, settings,
    etc.
2016-04-28 Add start and stop code
    Still need button LED behavior code and Pixel Ring code
2016-05-03 Make LED buttons pulse
    Buttons pulse twice upon press
2016-05-05 Include logger, buttons, and rings
    Does not currently function
2016-05-06 Troubleshoot memory issues
    Using the Timer library uses up too much RAM. Need to find a different
    method.
2016-05-06 Revert "Make LED buttons pulse"
    This reverts commit beebb84a9aded893c3256660bf9655a837656fe5.
    # Conflicts:
    # OnOffSwitch/GPSLogger/GPSLogger.ino
2016-05-06 Revert to working state
    LED buttons blink and GPS logs
2016-05-06 Combine buttons, ring, and GPS
    Everything works together, however, ring pauses when button pushed.
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2016-05-13 [Not working] Failed interpret attempt
    Purely used interrupts and RTC.
    [main.cpp]
2016-05-17 Create output files for second HES PCB revision
    [HalleffectSensorsStepFileRev2.step]
2016-05-18 [Untested] Reverted to a more basic strategy, still needs HW testing
    [main.cpp]
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2016-05-23 Create files for second HES PCB revision
    2.0 is sized for 20+/-AWG wire while 2.5 is sized for 18AWG
    [HalleffectSensorsStepFile2.step, HalleffectSensorsStepFile2_1.step]
2016-05-23 Include drill files for second HES PCB revision
2016-05-24 Improve calibration
    Code will not run until a start command is given. If that start command
    is a zero, it will skip calibration. This is useful if the EBox is power
    cycled but the winch is not.
    [WinchFSMrev4.ino]
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2016-06-01 [PDB] Fixed bug to change on boot
    [config.cpp, main.cpp]
2016-06-01 [PDB] Prevented RSSI overflow
    Adds a maximum delay of ~45mS when there is no RSSI signal.
    [config.cpp, main.cpp]
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2016-06-02 Create file to download and parse CTD data
    Downloads most recent data, appends it to a combined log file, and
    creates a file for the individual profile. NOTE: This version currently
    parses the data as well. Parsing will be done with a separate script in
    future revisions.
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2016-06-13 Added current measurements, decided ambient temperature sensor was accurate enough
    misc. documentation changes
2016-06-24 Initialize starting color to green
    LED ring starts out at half brightness green.
2016-06-24 Remove LEDs and improve stop/in code
    LEDs were breaking code and returning with stop-return now switches
    status to ready
2016-06-28 Made winch code less broken (accelerate)
    [accelerate.ino]
2016-06-28 Made winch not broken #2
    [accelerate.ino]
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2016-06-29 Initialize LED ring to off
    Uno was overheating with ring on. Will switch back to initializing on
    when new regulator is added.
2016-06-29 Create updated winch control program
    This version uses the changeSpeed() function to smoothly execute speed
    changes. It also closes some issues.
    [WinchControl2.0.ino]
2016-06-30 Resolved REV() issue
    called REV(depth) on the variable twice
    [WinchControl2.0.ino]
2016-07-05 CHANGE HES PINS TO REFLECT NEW AUX BOARD WIRING
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2016-07-22 Rewrite of the Ebox code, first commit.
    Was running out of ram on V1. Logging was sporadically failing, so
    moving on to V2 rewrite with more minimal libraries. GPS logging is
    solid and now separates logs into folders based on GPS date information.
    Serial comms are next.
    [OnOffSwitch_V2.ino]
2016-07-23 Main functionality now implemented
    Response to color change and brightness commands, as well as sending
    bytes for engine start and stop. Logging still functions as expected.
    Tested switch box on kayak, seems to be functioning.
2016-07-25 Engine start fix, undid start lockout
    Engine start and stop now match the interface file that was hidden (Nick
    :P). Undid the lockout for starting and stopping until we have feedback
    about the engine state. Tested on three boxes, now all working.
    [OnOffSwitch_V2.ino]
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2016-10-03 Separate maintain speed and lift speed
    The code now uses separate values for power when lifting the frame when
    returning from a cast and lifting the frame when maintaining.
2016-10-03 Revert 2.1 to last version to keep distinct from 2.2
    [WinchControl2.1_noLowerHES.ino]
2016-10-03 Create version for use with new ESC
    This version combines the desirable elements from the Alaksa revisions
    as well as sets the pulse widths to match the new ESC. See notes at top
    for necessary revisions.
2016-10-17 Create version of code that ramps slowly when lowering sensor
2016-10-24 Increase slowing distance
    Sensor begins to slow when 15 revolutions out, rather than 5.
2016-12-12 winch code for fishing rod (passive and PID)
    The passive code uses the fishing rod resistance only to detect when the CTD has hit the bottom. The PID code contains a PID loop to keep tension on the rod. Code was written before the resistance bo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
2017-01-04 Most recent stable PID winch code
    Some issues with the maintain STOP condition, abrupt when stopping. PID works, just needs to be tuned using live data.
    [WinchControl_XLX_green_PID_v4_Experimental.ino]
2017-01-05 Winch Code AS IS 1/4/17
    Winch code with working PID system, but that's about it right now.
2017-01-06 1_5_17_PID_Winch Arduino file
    Made file for most recent winch code
2017-01-12 Most recent PID winch version
    Changed Kp to be .035. Has a warning printing when the resistance is too high (too straight) after 5 seconds.
    [PID_Winch_1_10_2017.ino]
2017-01-17 PID values are customizable, sending warning message
    The PID values can now be customized using the 0xCD header value and the 2nd and 3rd values in the parameters array. (parameter[1] and parameter[2] also set as speedOut(Kp) and speedIn(Ki)). The boat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
